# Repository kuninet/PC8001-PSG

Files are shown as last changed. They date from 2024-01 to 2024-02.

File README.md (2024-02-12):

# PC8001-PSG (GSX8800風PSG音源ボード)

## 概要

* PC-8001用のPSGを2個搭載したボードです。
* I/OアドレスはGSX8800風(0A0h-0A3h or 0A4h-0A7h)にしてます。

  |I/Oアドレス|説明|
  |:--|:--|
  |0A0h(0A4h)|PSG#1 レジスタ番号|
  |0A1h(0A5h)|PSG#1 データ|
  |0A2h(0A6h)|PSG#2 レジスタ番号|
  |0A3h(0A7h)|PSG#2 データ|

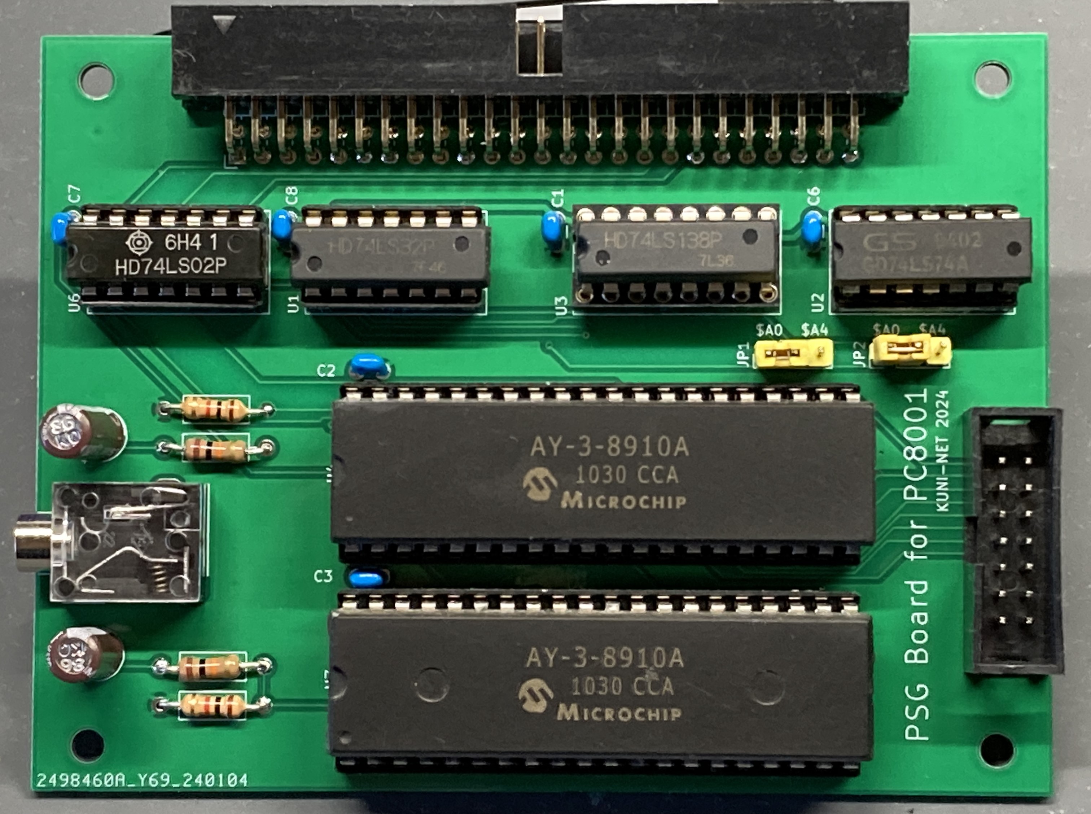
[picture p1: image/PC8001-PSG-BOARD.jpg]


## 回路図

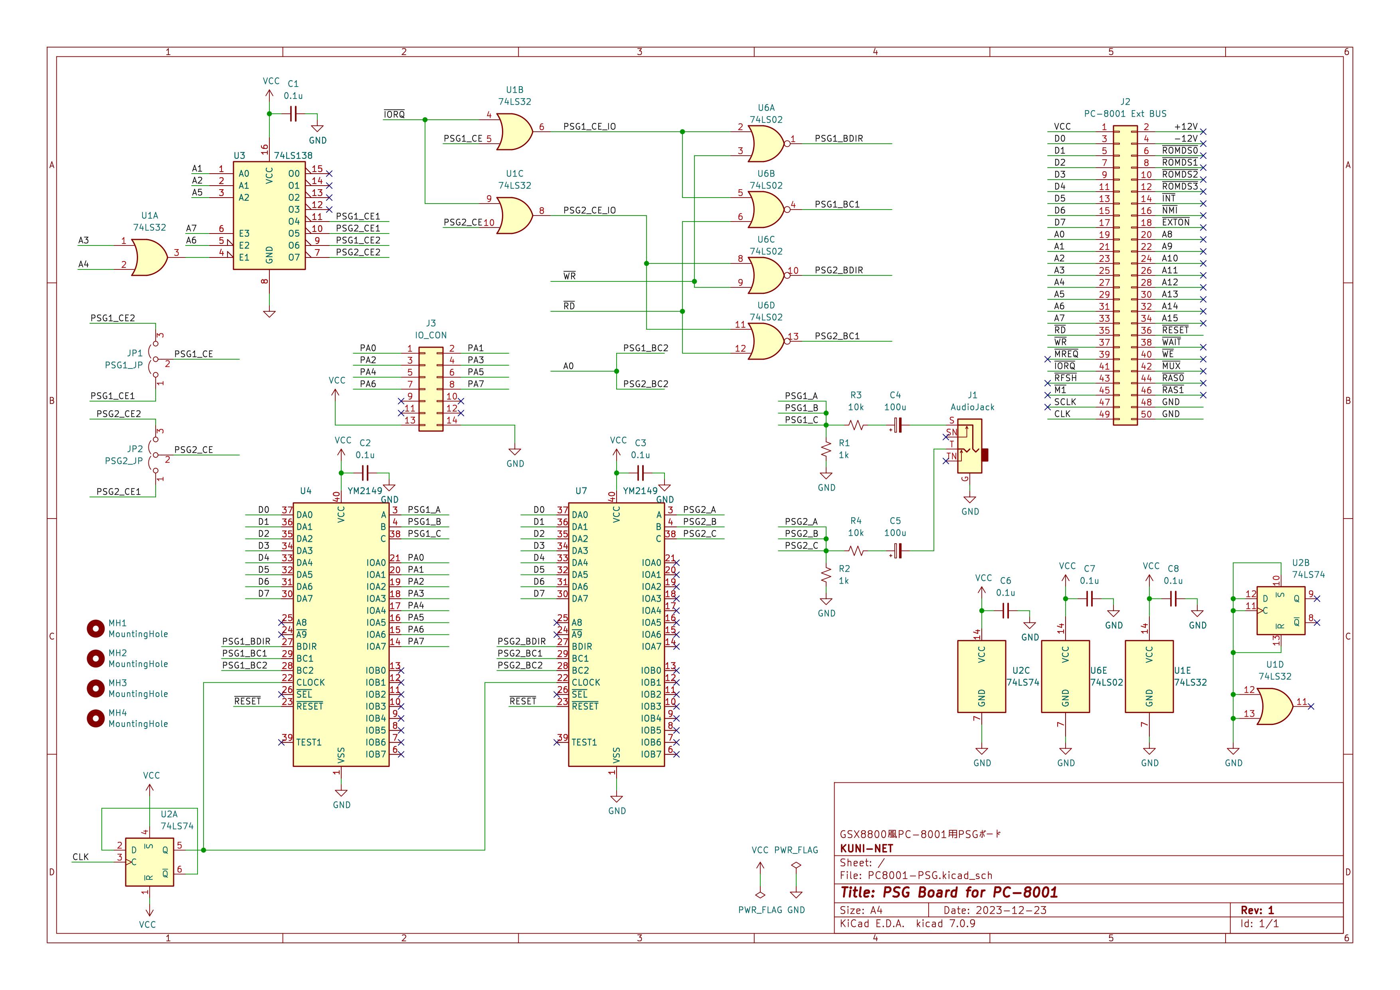
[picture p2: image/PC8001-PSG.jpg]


## ジャンパ設定

* I/Oアドレスを変更することが可能です。

  |JP|1-2|2-3|
  |:--|:--|:--|
  |JP1(PSG#1)|0A0h-0A1h|0A4h-0A5h|
  |JP2(PSG#2)|0A2h-0A3h|0A6h-0A7h|

## 部品表

[KiCad/PC8001-PSG.csv](KiCad/PC8001-PSG.csv)

## 参考URL

* https://piclabo.blog.ss-blog.jp/Simple8Z_PSG
  * SuperSimpleController（その２１）PSG(AY-3-8910A)の動作確認

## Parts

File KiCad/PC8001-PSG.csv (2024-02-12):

Item | Qty | Reference(s) | Value | Comments | LibPart | Footprint | Datasheet | DNP
1 | 6 | C1, C2, C3, C6, C7, C8 | 0.1u | セラミックコンデンサ | Device:C_Small | Capacitor_THT:C_Disc_D3.0mm_W1.6mm_P2.50mm | ~
2 | 2 | C4, C5 | 100u | 電解コンデンサ | Device:C_Polarized_Small | Capacitor_THT:CP_Radial_D5.0mm_P2.50mm | ~
3 | 1 | J1 | AJ-1780 | 基板取付用3.5mmステレオミニジャック | Connector_Audio:AudioJack2_Ground_Switch | AJ-1780:AJ-1780-2 | ~
4 | 1 | J2 | 50P ボックスヘッダ | 50P ボックスヘッダ | Connector_Generic:Conn_02x25_Odd_Even | Connector_PinHeader_2.54mm:PinHeader_2x25_P2.54mm_Horizontal | ~
5 | 1 | J3 | IO_CON | 2列 ピンヘッダ | Connector_Generic:Conn_02x07_Odd_Even | Connector_PinHeader_2.54mm:PinHeader_2x07_P2.54mm_Vertical | ~
6 | 1 | JP1 | PSG1_JP | 1列 ピンヘッダ | Jumper:Jumper_3_Open | Connector_PinHeader_2.54mm:PinHeader_1x03_P2.54mm_Vertical | ~
7 | 1 | JP2 | PSG2_JP | 1列 ピンヘッダ | Jumper:Jumper_3_Open | Connector_PinHeader_2.54mm:PinHeader_1x03_P2.54mm_Vertical | ~
8 | 4 | MH1, MH2, MH3, MH4 | MountingHole | 基板穴(部品ではありません) | Mechanical:MountingHole | MountingHole:MountingHole_3.2mm_M3 | ~
9 | 2 | R1, R2 | 1k | 抵抗器 | Device:R_Small_US | Resistor_THT:R_Axial_DIN0207_L6.3mm_D2.5mm_P10.16mm_Horizontal | ~
10 | 2 | R3, R4 | 10k | 抵抗器 | Device:R_Small_US | Resistor_THT:R_Axial_DIN0207_L6.3mm_D2.5mm_P10.16mm_Horizontal | ~
11 | 1 | U1 | 74LS32 | ロジックIC | 74xx:74LS32 | Package_DIP:DIP-14_W7.62mm_Socket | http://www.ti.com/lit/gpn/sn74LS32
12 | 1 | U2 | 74LS74 | ロジックIC | 74xx:74LS74 | Package_DIP:DIP-14_W7.62mm_Socket | 74xx/74hc_hct74.pdf
13 | 1 | U3 | 74LS138 | ロジックIC | 74xx:74LS138 | Package_DIP:DIP-16_W7.62mm_Socket | http://www.ti.com/lit/gpn/sn74LS138
14 | 2 | U4, U7 | YM2149 | 音源IC | Audio:YM2149 | Package_DIP:DIP-40_W15.24mm | http://www.ym2149.com/ym2149.pdf
15 | 1 | U6 | 74LS02 | ロジックIC | 74xx:74LS02 | Package_DIP:DIP-14_W7.62mm_Socket | http://www.ti.com/lit/gpn/sn74ls02

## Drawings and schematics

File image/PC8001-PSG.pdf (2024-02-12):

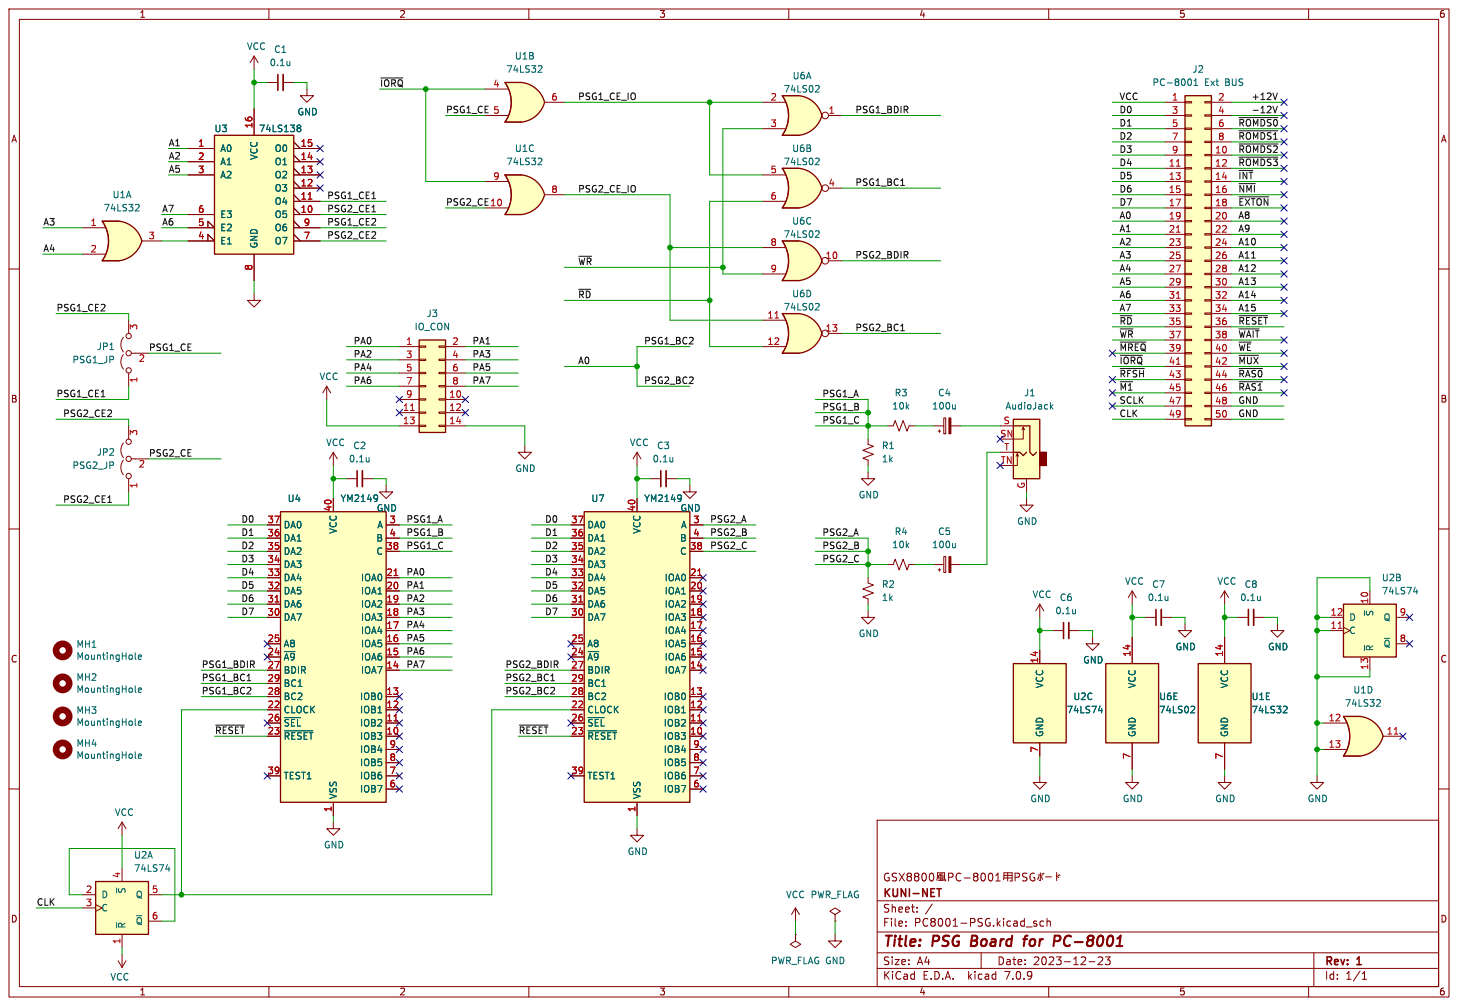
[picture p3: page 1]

File: PC8001-PSG.kicad_sch Sheet: / KUNI-NET

Id: 1/1 Title: PSG Board for PC-8001

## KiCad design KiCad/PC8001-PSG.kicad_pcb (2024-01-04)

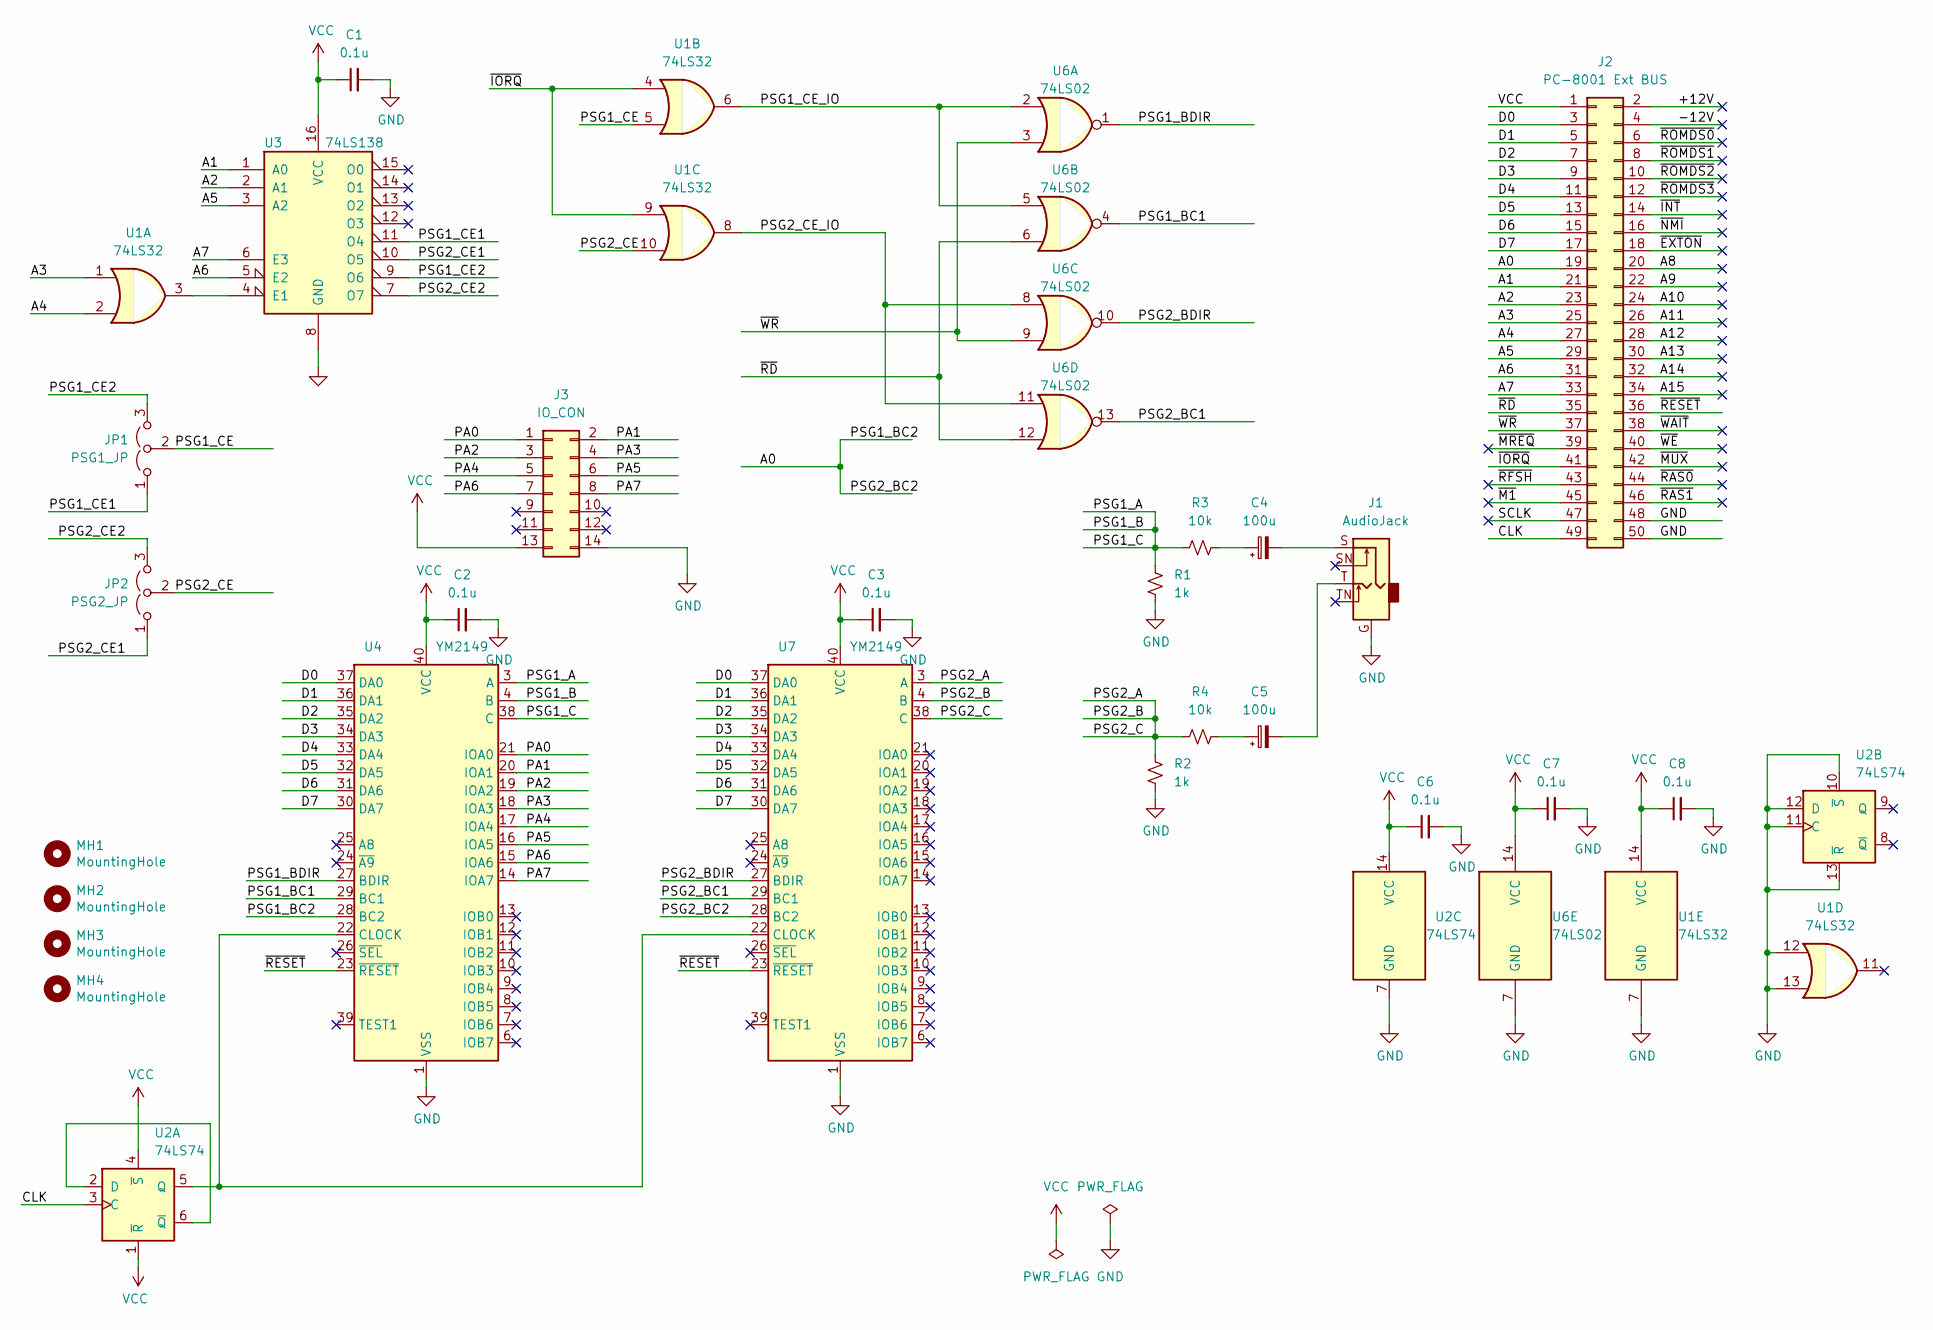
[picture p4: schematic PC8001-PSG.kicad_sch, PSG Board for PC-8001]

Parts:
C1, C2, C3, C6, C7, C8: 0.1u; C_Disc_D3.0mm_W1.6mm_P2.50mm
C4, C5: 100u; CP_Radial_D5.0mm_P2.50mm
J1: AudioJack; AJ-1780-2
J2: PC-8001 Ext BUS; PinHeader_2x25_P2.54mm_Horizontal
J3: IO_CON; PinHeader_2x07_P2.54mm_Vertical
JP1: PSG1_JP; PinHeader_1x03_P2.54mm_Vertical
JP2: PSG2_JP; PinHeader_1x03_P2.54mm_Vertical
MH1, MH2, MH3, MH4: MountingHole; MountingHole_3.2mm_M3
R1, R2: 1k; R_Axial_DIN0207_L6.3mm_D2.5mm_P10.16mm_Horizontal
R3, R4: 10k; R_Axial_DIN0207_L6.3mm_D2.5mm_P10.16mm_Horizontal
U1: 74LS32; DIP-14_W7.62mm_Socket
U2: 74LS74; DIP-14_W7.62mm_Socket
U3: 74LS138; DIP-16_W7.62mm_Socket
U4, U7: YM2149; DIP-40_W15.24mm
U6: 74LS02; DIP-14_W7.62mm_Socket

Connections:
/+12V: J2.2
/-12V: J2.4
/A0: J2.19, U4.28 (BC2), U7.28 (BC2)
/A1: J2.21, U3.1 (A0)
/A2: J2.23, U3.2 (A1)
/A3: J2.25, U1.1
/A4: J2.27, U1.2
/A5: J2.29, U3.3 (A2)
/A6: J2.31, U3.5 (E2)
/A7: J2.33, U3.6 (E3)
/A8: J2.20
/A9: J2.22
/A10: J2.24
/A11: J2.26
/A12: J2.28
/A13: J2.30
/A14: J2.32
/A15: J2.34
/CLK: J2.49, U2.3 (C)
/D0: J2.3, U4.37 (DA0), U7.37 (DA0)
/D1: J2.5, U4.36 (DA1), U7.36 (DA1)
/D2: J2.7, U4.35 (DA2), U7.35 (DA2)
/D3: J2.9, U4.34 (DA3), U7.34 (DA3)
/D4: J2.11, U4.33 (DA4), U7.33 (DA4)
/D5: J2.13, U4.32 (DA5), U7.32 (DA5)
/D6: J2.15, U4.31 (DA6), U7.31 (DA6)
/D7: J2.17, U4.30 (DA7), U7.30 (DA7)
/PA0: J3.1, U4.21 (IOA0)
/PA1: J3.2, U4.20 (IOA1)
/PA2: J3.3, U4.19 (IOA2)
/PA3: J3.4, U4.18 (IOA3)
/PA4: J3.5, U4.17 (IOA4)
/PA5: J3.6, U4.16 (IOA5)
/PA6: J3.7, U4.15 (IOA6)
/PA7: J3.8, U4.14 (IOA7)
/PSG1_A: R1.2, R3.1, U4.3 (A), U4.4 (B), U4.38 (C)
/PSG1_BC1: U4.29 (BC1), U6.4
/PSG1_BDIR: U4.27 (BDIR), U6.1
/PSG1_CE: JP1.2 (C), U1.5
/PSG1_CE1: JP1.1 (A), U3.11 (O4)
/PSG1_CE2: JP1.3 (B), U3.9 (O6)
/PSG1_CE_IO: U1.6, U6.2, U6.5
/PSG2_A: R2.2, R4.1, U7.3 (A), U7.4 (B), U7.38 (C)
/PSG2_BC1: U6.13, U7.29 (BC1)
/PSG2_BDIR: U6.10, U7.27 (BDIR)
/PSG2_CE: JP2.2 (C), U1.10
/PSG2_CE1: JP2.1 (A), U3.10 (O5)
/PSG2_CE2: JP2.3 (B), U3.7 (O7)
/PSG2_CE_IO: U1.8, U6.8, U6.11
/SCLK: J2.47
/~EXTON: J2.18
/~INT: J2.14
/~IORQ: J2.41, U1.4, U1.9
/~M1: J2.45
/~MREQ: J2.39
/~MUX: J2.42
/~NMI: J2.16
/~RAS0: J2.44
/~RAS1: J2.46
/~RD: J2.35, U6.6, U6.12
/~RESET: J2.36, U4.23 (~RESET), U7.23 (~RESET)
/~RFSH: J2.43
/~ROMDS0: J2.6
/~ROMDS1: J2.8
/~ROMDS2: J2.10
/~ROMDS3: J2.12
/~WAIT: J2.38
/~WE: J2.40
/~WR: J2.37, U6.3, U6.9
GND: C1.2, C2.2, C3.2, C6.2, C7.2, C8.2, J1.G, J2.48, J2.50, J3.14, R1.1, R2.1, U1.7 (GND), U1.12, U1.13, U2.7 (GND), U2.10 (~S), U2.11 (C), U2.12 (D), U2.13 (~R), U3.8 (GND), U4.1 (VSS), U6.7 (GND), U7.1 (VSS)
unnamed: C4.1, R3.2
unnamed: C4.2, J1.S
unnamed: C5.1, R4.2
unnamed: C5.2, J1.T
unnamed: U2.2 (D), U2.6 (~Q)
unnamed: U2.5 (Q), U4.22 (CLOCK), U7.22 (CLOCK)
unnamed: U1.3, U3.4 (E1)
VCC: C1.1, C2.1, C3.1, C6.1, C7.1, C8.1, J2.1, J3.13, U1.14 (VCC), U2.1 (~R), U2.4 (~S), U2.14 (VCC), U3.16 (VCC), U4.40 (VCC), U6.14 (VCC), U7.40 (VCC)

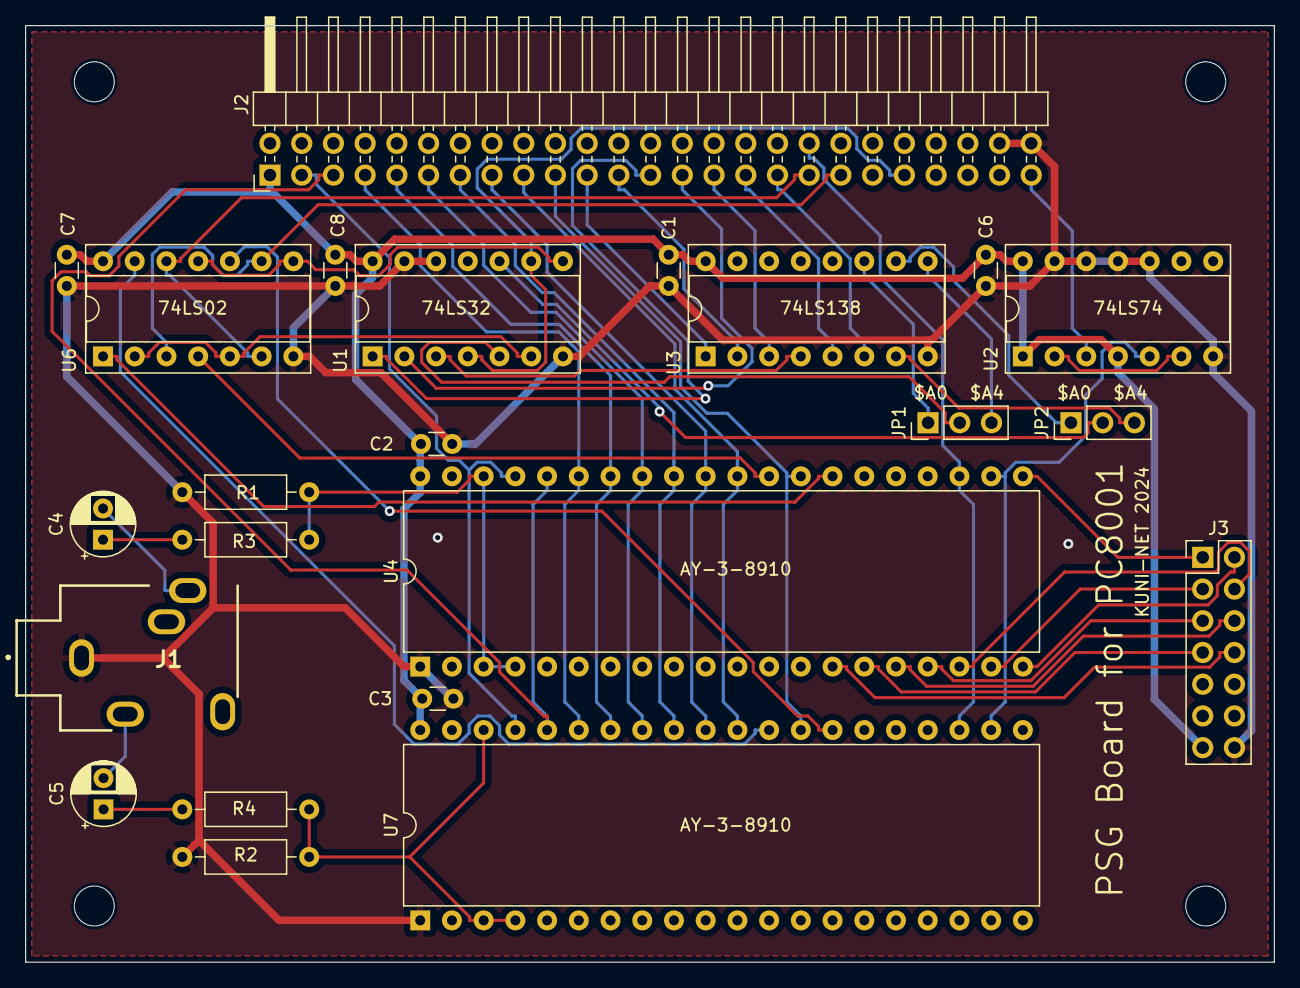
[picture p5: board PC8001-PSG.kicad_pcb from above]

Board: 2 copper layers, 100.0 x 75.0 mm, 27 parts (0 on the bottom side), 52 nets.

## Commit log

2023-12-23 回路図初版
    [PC8001-PSG.kicad_pcb, PC8001-PSG.kicad_sch]
2024-01-03 プリントパターン等検討、ガーバー出力
    [PC8001-PSG.GBL, PC8001-PSG.GBO, PC8001-PSG.GBP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]
2024-01-04 AJ-1780フットプリント修正 & ガーバーデータ再出力
    [PC8001-PSG.GBL, PC8001-PSG.GBO, PC8001-PSG.GBP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]
2024-02-12 部品表追加、README更新
    [PC8001-PSG.csv]
